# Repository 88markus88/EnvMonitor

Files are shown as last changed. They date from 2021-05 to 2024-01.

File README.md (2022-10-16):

# EnvMonitor - ESP32
This project aims to create an environmental monitoring system, using ESP32 and multiple environmental sensors and make the data visible using <B>Blynk</B> (https://blynk.io/)

The project consists of both software code and the hardware description as KiCad and (partly) Fritzing files.

It is work in progress, but already functional. Development is being done using Platformio with the Arduino platform. 
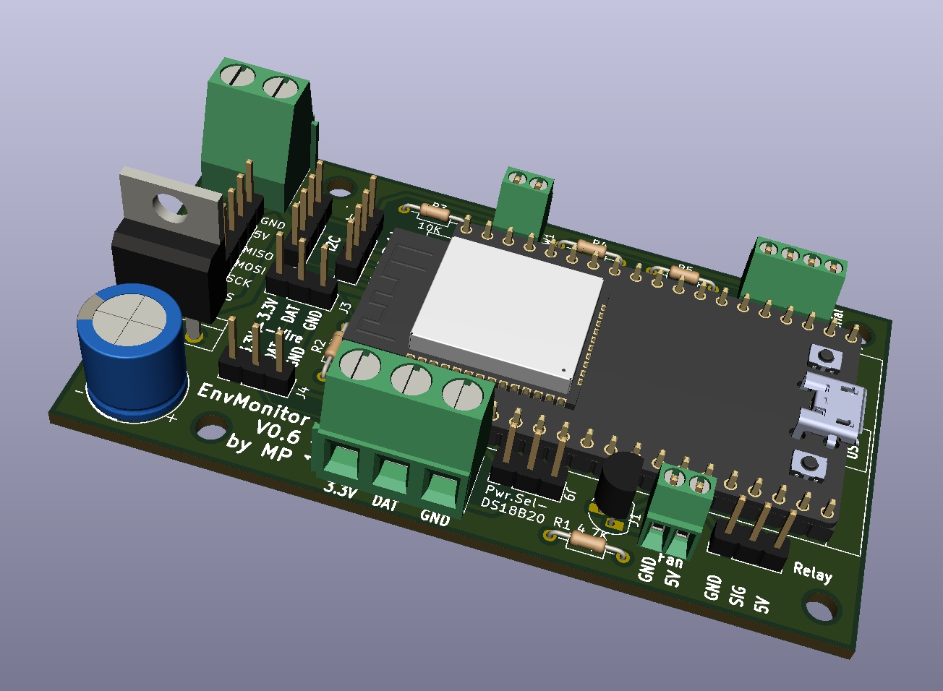
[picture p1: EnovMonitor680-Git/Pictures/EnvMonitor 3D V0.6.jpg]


## Visualization:
Visualization is done via Blynk, a commercial service that can also be used with a local server, e.g. on a Raspberry Pi
All data that the EnvMonitor provides can be shown via the Blynk App - very simple and powerful. Since the service is cloud based, the data can be viewed at every location.
Blynk also supports a local server (e.g. on a Raspberry) - this eliminates the costs for the Blynk service.

Support is also implemented for Thingspeak (all devices) and for Virtuino (early prototype).
Thingspeak is one-way only for BME280, BME600, DS18B20, 433 MHz external sensors and CO2 sensors. Each ESP32 board can be connected to one Thingspeak channel, up to 8 data per devices (data streams) are supported by Thingspeak.

## Sensors:
So far the following sensors and devices on the following list can be included. Selection is done by modification of the #defines in *GlobalDefines.h*:
- BME280 (Temperature / Humidity / Pressure) via I2C
- BME680 (Temperature / Humidity / Pressure / Air Quality) via I2C
- DS18B20 (Temperature, up to 3 sensors) via OneWire
- MH-Z14A (CO2) via Serial2
- SenseAir S8 (CO2) via Serial2
- External temperature and humidity data from an Infactory NV5849 433MHz transmitter connected to an Arduino via Serial2
- Infactory NV5849 (433 MHz Temperature / Humidity sender) directly received via 433MHz receiver at GPIO 33. This option is supported by the software, ut not implemented on the board. 

## Devices:
- Relays / Transistor switches (2). Used for fan and for piezo buzzers.
- OLED Display 0.94" (SS1306) via I2C
- LCD Display 4 x 20 via I2C
- Button to be able to switch content of displays, or mute display light
- SD card reader via SPI

## ESP32 Hardware
The main component is an ESP32 with various peripherals attached. Communication to the peripherals is done via 
- 1Wire (DS180B20 temperature sensors)
- I2C (OLE or LCD displays, BME280 or BME 680 environment sensors
- SPI (SD card drive)
- Serial (CO2 sensors, external sensors via Arduino)
- GPIOs (button, transistor or relais)

All components are optional. They can be used in a large varity of combinations, providing that there are no confliting requirements
- Multiple devices can be combined on the I2C interface. E.g. BME280 and OLED display can be used together. Or LCD display and BME680. Or BME280 and no display.
- Up to 3 DS18B20 temperature sensors are supported. 3 connectors are provided, where they are connected in parallel. 
- Only one serial port (Serial2) is supported. Therefore only one CO2 sensor, or alternatively one Arduino, can be connected.
- Running a fan, piezo buzzer etc. via BC547 transistor, or other devices via relay, is supported by the hardware. Can also be used for a buzzer which gives an alarm uf window remains open too long.
- An internal power source can be used, which requires 7V-36V input from an external power supply.
Components that are not used do not have to be placed on the board. They can be configured out in the software via #defines

The board can be powered via USB. However, the USB power is relatively unstable. Most USB power supplies are not stabilized and should not be used, at least with multiple components connected - this can lead to brownouts and system failure. Raspberry Pi power supplies are better suited. 
Best is to use the option to add an internal DCDC converter <I>Traco TSR 1-2450E</I> that can be driven with 7-36V and provides excellent power conditioning. If this is not chosen, just leave the components (DCDC converter, capacitor, diode, terminal block) out.

It is possible to receive data from a 433 MHz transmitter via serial (e.g. received from an Arduino). (The serial port is not included in the Fritzing drawing.) 
The Arduino board, as well as it's software are described in a separate section. 

The board allows power selection for the 1Wire bus: either directly from 3.3V, or via GPIO32 of the ESP32. (In default configuration each GPIO can drive 20 mA).
This is useful to be able to completely reset the 1Wire bus - often necessary if cheap DS18B20 ("fake sensors") are being used. These have a tendency to hang after extended use, the only viable option is then to completely cut the power.

KiCad files are provided for the electrical schemas and the PCB boards. 

There is also a Fritzing file for illustration, however it is not complete: it does not contain the option to connect a 433 MHz transmitter. It also does not contain the external power supply that has been included in KiCad, and the option to power the DS18B20 sensors via digital output 32 (Jumper on J9) as an alternative to 3.3V. This may be necessary if the sensors are too unstable for continued operation, they can then optionally be reset by switching their power supply. May be necessary since most available DS18B20s are fake and prone to unstability (no data for longer periods). First option in this case is the reduction of the pulllup resistor R2 to 2.5K.

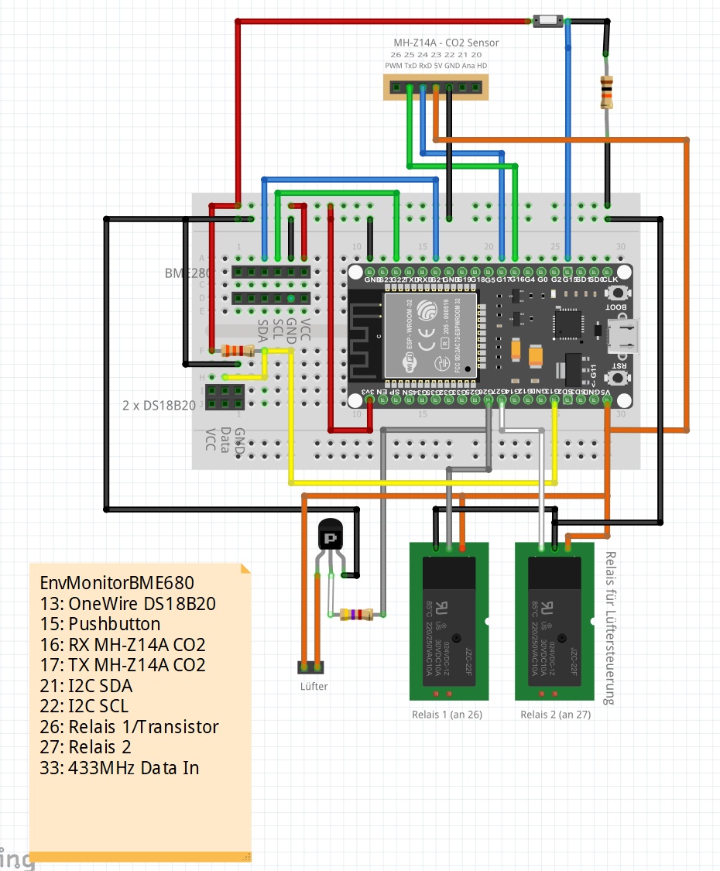
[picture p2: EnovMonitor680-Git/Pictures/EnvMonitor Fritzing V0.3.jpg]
Fritzing

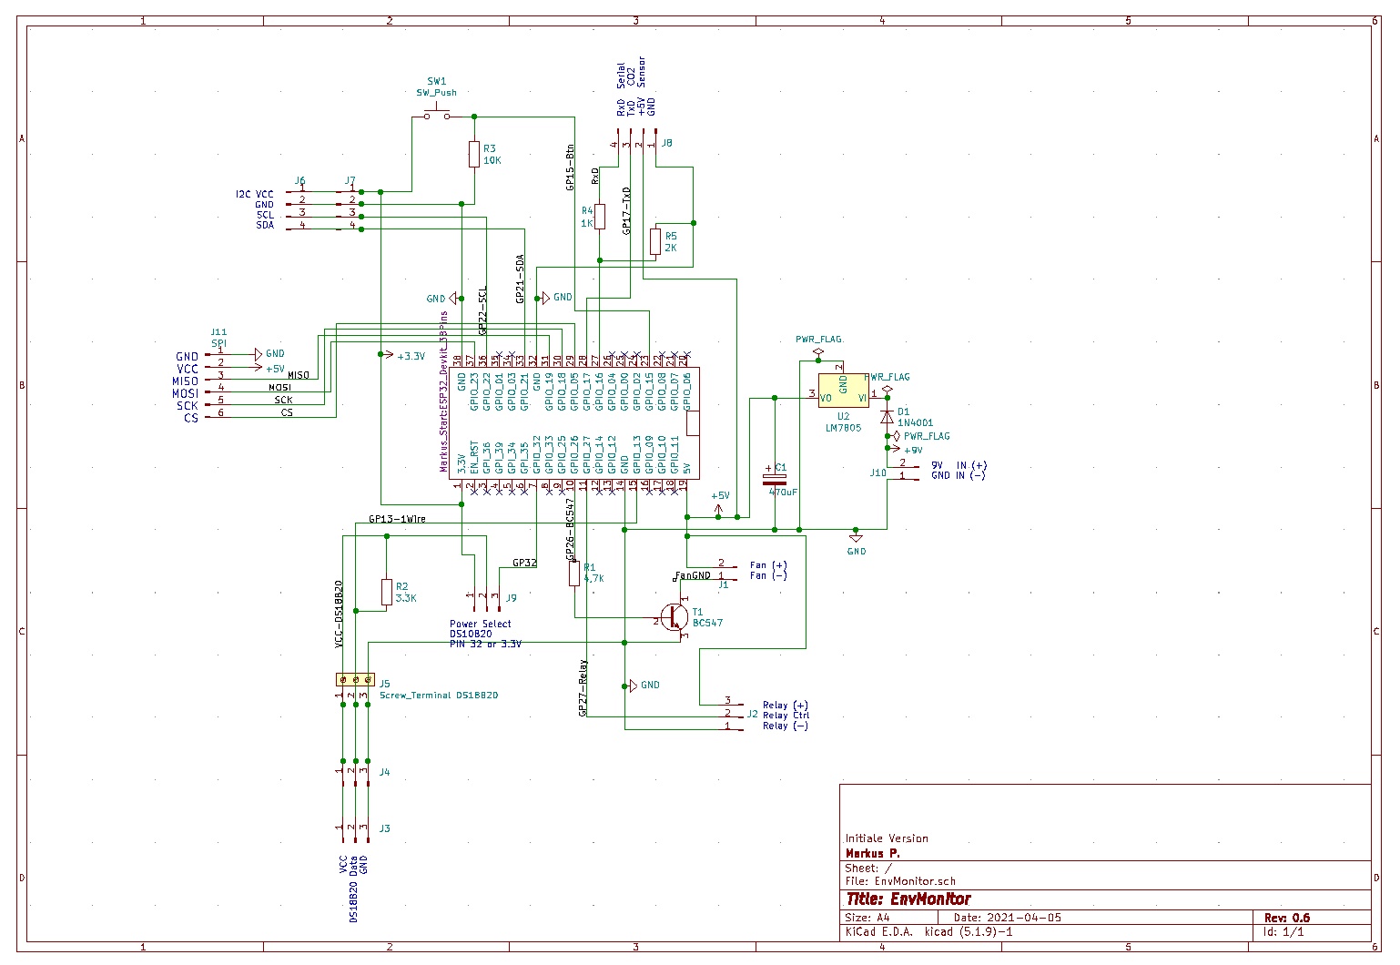
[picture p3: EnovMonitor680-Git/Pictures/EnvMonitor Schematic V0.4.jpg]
Schema

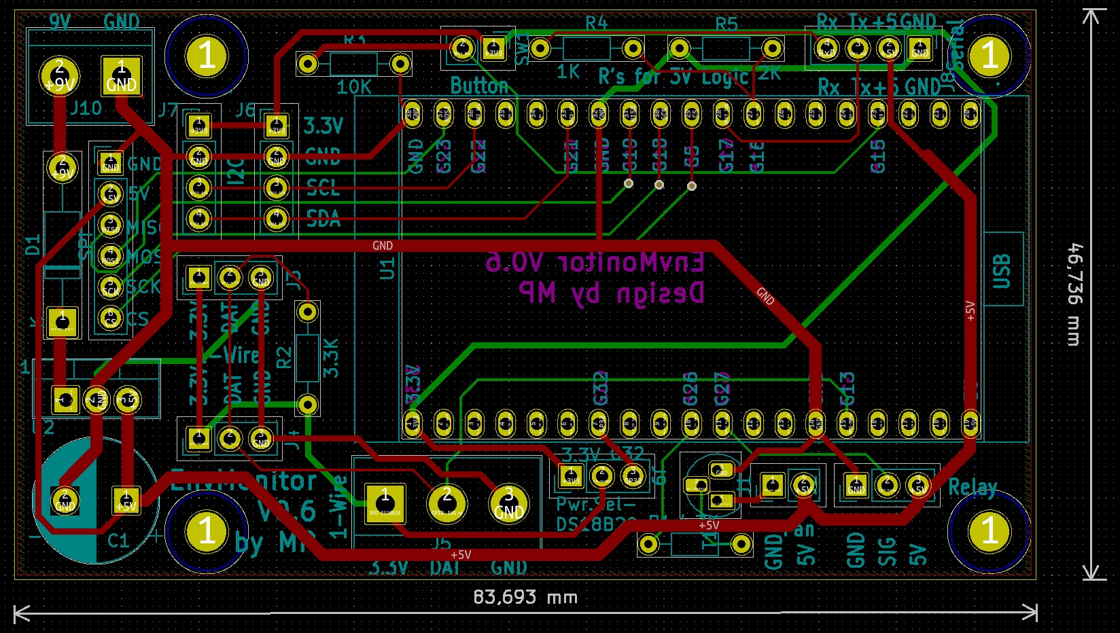
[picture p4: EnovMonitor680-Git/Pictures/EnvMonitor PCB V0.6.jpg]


## ESP32 Code
The code is written in C++. It is intended to be flexible, to allow almost any combination of sensors and displays on the board. 
All data are sent to a Blynk server, provided that *#define isBlynk* is set.

Development platform is Platformio. The code should also compile - with minimum adaptations - on the Arduino IDE. However, Platformio is much more flexible, compile times much faster due to more efficient built. It is well worth to switch to Platformio!

In order to compile the code, the following adaptations have to be made:
1. Get the required libraries, adjust the library path in *platformio.ini* to point to your library directory
2. create your own *Credentials.h* file. A template file is provided. You need to put in the name and password for your Wifi network, this is a must to allow the ESP32 to access the network. Then insert the auth code, temperature correction data and device info strings for each device you want to use. This file can contain any number of these device definitions, each within a #ifdef /#endif construct.
3. Adapt "GlobalDefines.h" to your hardware.  
  - enter the IP address of your local Blynk server
  - set one #define for the name of the hardware configuration you want to use (one of those in the "credentials.h" file)
  - set the actual hardware definitions: use of Blynk, use of sensors, use of display etc. These hardware definitions must fit the ones set in *credentials.h*
  - determine if you want to log to a SD card and / or to the serial port
  - determine if OTA (over the air) updates shall be used
 4. modify *platformio.ini* as needed: set _default_envs_ to determine which environment is to be used. This is largely required to determine if USB  upload or OTA upload to a given IP are to be used.

## Libraries
For listing of used libraries see 
See  [Libraries](https://github.com/88markus88/EnvMonitor/blob/main/EnovMonitor680-Git/Doc/Libraries.md)

## Connectivity 
In order to transmit data to a web service the ESP32 needs to log into a local network. At present, three services can be supported
- <b>Blynk</b>: Commercial service to which the data are sent, and shown on mobile device in an app that can be configured very fleibly. The data can either be sent to the Blynk web service or to a local server. fully implemented for all data. Temperature, Humidity, Pressure etc. for all sensors are transmitted via "Virtual Pins" (see below for details). Blynk Auth Codes, which are specific for any devices and generated within the Blynk App on a mobile device, need to be put into the file <i>Credentials.h</i>
<b>Notice</b> Blynk is presently transitioning to V2.0 with much more expensive licensing models, and no local server. Makes it less desirably for hobbyist users, consider Thingspeak as an alternative.
- <b>Virtuino</b>: (Experimental) Similar solution to Blynk. However, here the device itself provides a web server into which the mobile has to log in. Only partly implemented for demonstration purposes.
- <b>Thingspeak</b>: Web service that stores sensor data and makes them available to a variety of generic mobile apps. Data for all devices and sensors (BME680, BME280, CO2 Sensors and DS18B20 can be transmitted, as well as data from 433 MHz radio sensors for temperature and humidity. Thingspeak is addressed via a https call to an address that encodes the Write API Key defined for a specific device, there can be up to 8 data channels per device. The channel to be used is encoded via  <i>thingspeakWriteAPIKey</i>. Limitation are the up to 8 data items per channel and max 4 channels (=devices) per user in the free version. Also, the data rate is limited for the free version. This is taken care of by filtering the data to thingspeak, they are only updated if a significant change has been registered.
Blynk and Thingspeak can be used in parallel on a device. 
Settings which connecitivity type is used are done in <i>GlobalDefines.h</i> via the #defines isBLYNK, isThingspeak, isVirtuino. 

### Setting the WiFi Credentials
To access the local network the ESP32 requires the network credentials, particularly the SSID and password. They could be encoded in source code, and indeed default data are included in <i>Credentials.h</i>. However, this method is very clumsy - it requires re-compile of the code every time the credentials are changed, or a new network is used. Therefore, two methods are provided to update the credentials at runtime, and store them in the Preferences (ESP32 EEPROM):
- <b>Captive Portal</b> Activated by the #define <i>isCaptivePortal</i>. If this is set, the device goes through a sequence at bootup: 
1. If Wifi login with valid credentials are stored in the preferences, these are used
2. If not, the captive portal is opened, the user can select a network and provide the password. If login with these data is possible, these credentials are stored in the preferences for future use. The default SSID for the captive portal is <i>ESP_Config</i>  , the default password is <i>12345678</i>
3. If neither works, the defaults are used (but not stores, since the network may be out temporarily)
- <b>Bluetooth</b> Activated by the #define <i>isBluetoothCredentials</i>. When activated, the ESP32 waits for 60 sec after Boot for a connection from a mobile device. In a Bluetooth terminal app on the mobile, the user can then connect to the device, and enter the credentials: <i>ssid:[id_of_your_network]<i/> <i>pass:[your_password]<i/>. These credentials are then stored in the Preferences and used in future logins

### Blynk Virtual Pins
Blynk uses the concept of __Virtual Pins__ for communication between the hardware devices and App (via the server). The list of virtual pins in actual use depends on the sensors that are implemented on a specific devices. They need to be known in order to connect the Widgets within the App to specific sensors.

See [List of Virtual Pins](https://github.com/88markus88/EnvMonitor/blob/main/EnovMonitor680-Git/Doc/BlynkVirtualPins.md)

# Arduino
PCB and Code for the Arduino Nano that can provide the data from an external 433MHz sensor is also included.
Why using and Arduino? It turns out that the Wifi used by the ESP32 interferes with the 433 MHz reception when an ESP32 is used directly. The signals are disturbed by the 100 ms heartbeat of the Wifi that cannot be changed easily. 
So a small arduino PCB and sketch have been developed to still be able to use external 433MHz sensors. This Arduino needs to be connected via cable to the ESP32. Pins used for this are +5V, GND, RxD and TxD (the latter switched between ESP32 and Arduino)
No special libraries are needed for the Arduino Sketch. 

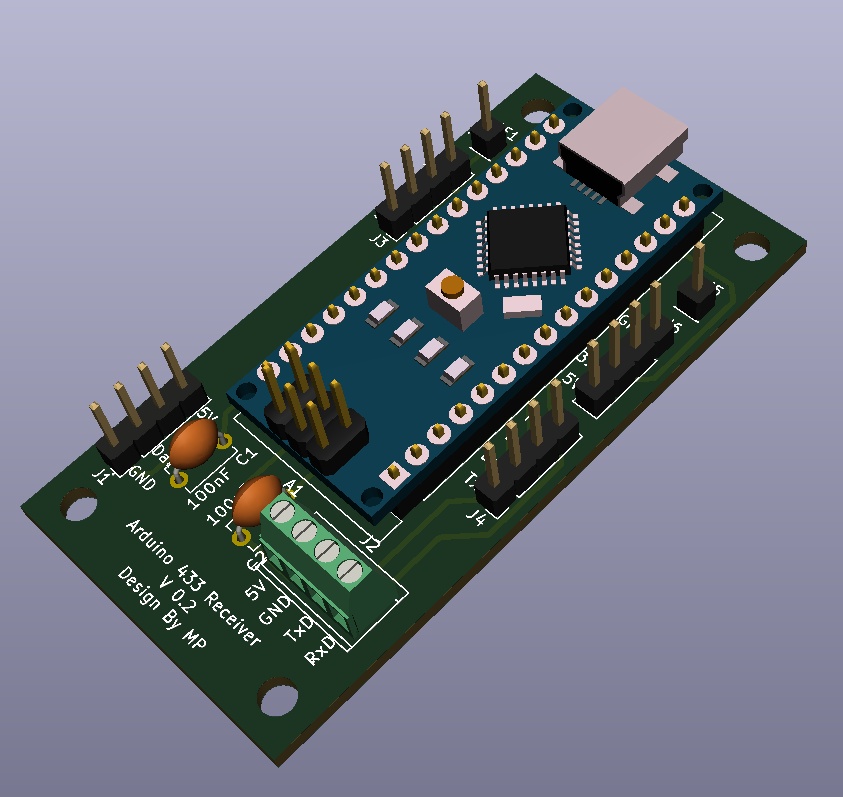
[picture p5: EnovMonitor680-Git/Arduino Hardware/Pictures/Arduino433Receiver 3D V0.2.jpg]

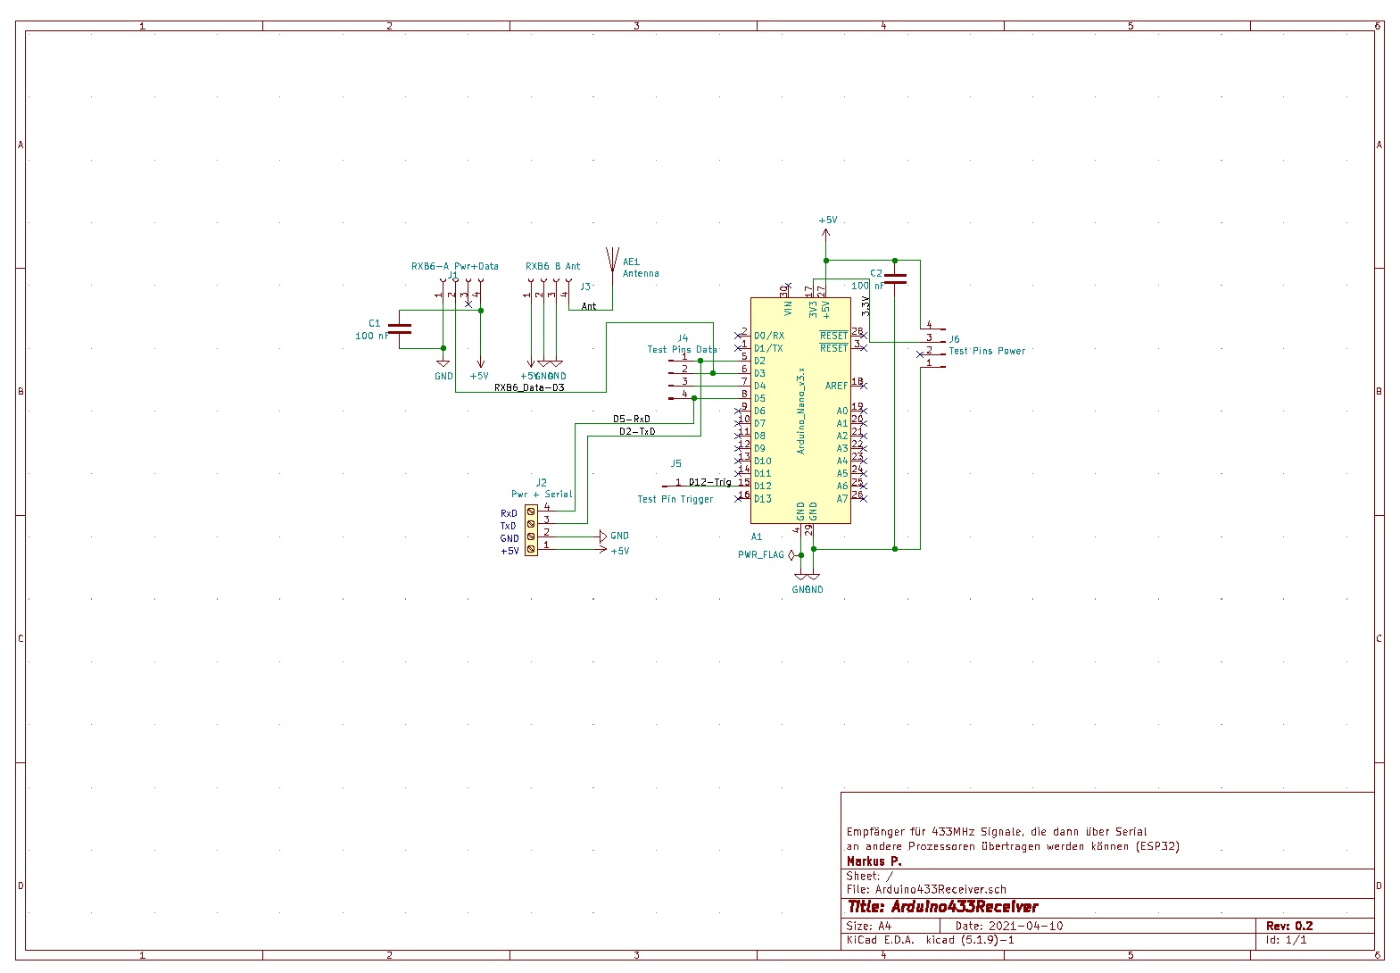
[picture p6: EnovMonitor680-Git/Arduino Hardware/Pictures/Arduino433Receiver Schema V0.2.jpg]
Schema

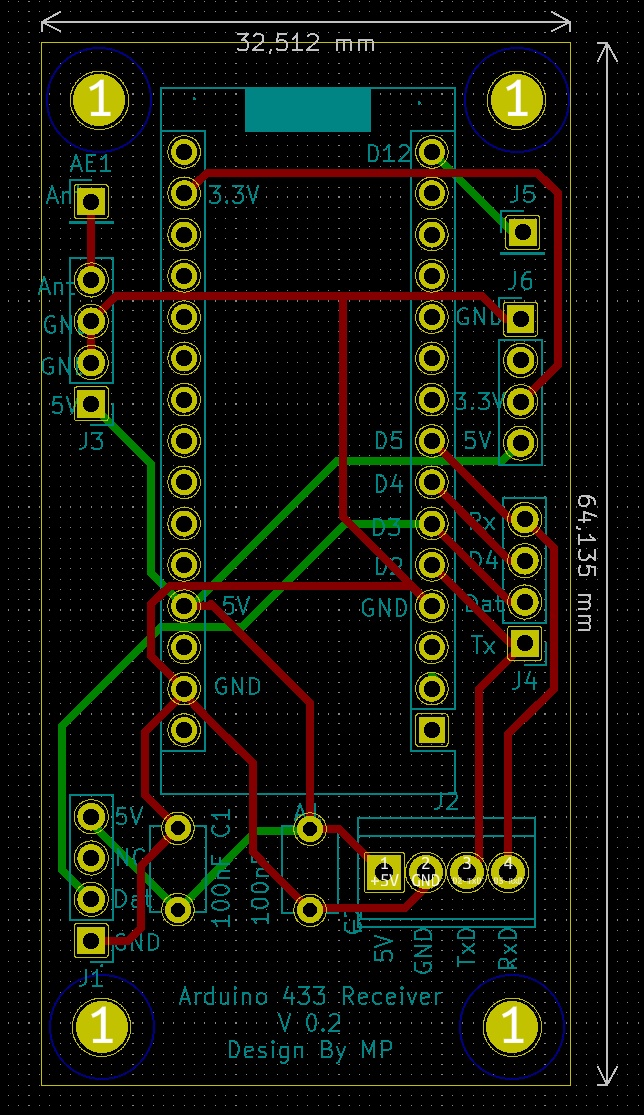
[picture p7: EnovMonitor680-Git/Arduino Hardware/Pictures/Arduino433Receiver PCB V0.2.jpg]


## Parts
See [Parts List](https://github.com/88markus88/EnvMonitor/blob/main/EnovMonitor680-Git/Doc/Partslist.md)

## GPIO Pins
A number of ESP32 I/O Pins are used. 
See  [List of GPIO Pins](https://github.com/88markus88/EnvMonitor/blob/main/EnovMonitor680-Git/Doc/GPIOs.md)

## Credits
- Blynk Library from here: https://blynk.io/. Using <i>Wifi, WifiClient</i> and <i>BlynkSimpleEsp32</i> libraries
- BME 280: <i>Wire</i>, <i>Adafruit_Sensor</i> and <i>Adafruit_BME280</i> libraries
- BME 680: using <i>Zanshin_BME680</i> and <i>SPI</i> libraries by Arnd SV Zanshin, https://github.com/Zanduino/BME680  and Information from this Article https://wiki.dfrobot.com/Gravity__I2C_BME680_Environmental_Sensor__VOC,_Temperature,_Humidity,_Barometer__SKU__SEN0248 <br>
  Alternatively: BME 680 using the manufacturer supplied __BSEC__ library by Bosch Sensortec. This library is only available as pre-compiled object code. https://platformio.org/lib/show/6979/BSEC%20Software%20Library 
- NTP time using info from: https://randomnerdtutorials.com/esp32-date-time-ntp-client-server-arduino/ 
- OLED display: using <i>Adafruit_GFX</i> and <i>Adafruit_SSD1306</i> libraries
- DS18B20: using <i>OneWire</i> and <i>DallasTemperature</i> libraries
- SenseAir S8: using code from SFeli https://github.com/SFeli/ESP32_S8  
- MH-Z14A_ using code from the contributin by Mitch K https://www.hackster.io/kritch83/getting-started-with-the-mh-z14a-co2-detector-e96234 
- Infactory NV5849: based on work and code by Ray Wang https://rayshobby.net/reverse-engineer-wireless-temperature-humidity-rain-sensors-part-1/ 
- Macros for bit field manipulation by Shun Yan Cheung: http://www.mathcs.emory.edu/~cheung/Courses/255/Syllabus/1-C-intro/bit-array.html
- LCD library from Marco Schwartz: <i>LiquidCrystal_I2C</i> : https://github.com/marcoschwartz/LiquidCrystal_I2C/archive/master.zip

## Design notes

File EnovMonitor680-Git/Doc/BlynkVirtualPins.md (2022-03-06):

#Blynk Virtual Pins

The Blynk App receives data from Virtual Pins, and sends data to Virtual Pins.
The ESP32 program has to handle the same Virtual Pins via 
- BLYNK_WRITE - from App to ESP32
- Blynk.virtualwrite - from ESP32 to App
These data are provided via a Blynk server. This can either be the Blynk Cloud service, at a cost per widget, or on a local server.

More Information is available on the [Blynk Website](https://blynk.io/)

These virtual Pins are used by EnvMonitor:

**Inputs**
VPin  |Function
------|---------
V40 | Relay 1 (was V18)
V41 | Relay 2 (was V19)
V42 | tempSwitchOffset (Fan on if temp BS680 this much too high)
V20 | Start CO2 Sensor Calibration
V60 | Manual restart of 1Wire bus (DS18B20 Sensors)
V70 | Used for data transfer by bridge1. Transfer temperature alerts.
V80 | Used for data transfer by bridge2. Transfer temperature alerts.

**Outputs**
VPin  |Function
------|---------
V1  | Wifi Signal strength (RSSI)
V5  | BME280 / BME680 Temperature
V6  | BME280 / BME680 Air Pressure
V7  | BME280 / BME680 Humidity
V8  | BME680 Air Quality Score
V12 | BME680 Air Quality String
V13 | DS18B20[0]  Temperature
V10 | DS18B20[1]  Temperature
V11 | DS18B20[2]  Temperature
V15 | Infactory Temperature Ch1
V16 | Infactory Humidity Ch1
V17 | Infactory Temperatue Ch2
V18 | Infactory Humidity Ch2
V19 | Infactory Temperature Ch3
V20 | Infactory Humidity Ch3
V35 | Infactory Ch1 Counter 
V36 | Infactory Ch2 Counter 
V37 | Infactory Ch3 Counter 
V38 | Infactory Serial Fail Counter

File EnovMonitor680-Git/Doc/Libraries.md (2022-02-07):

# EnvMonitor 

## Libraries
The libraries for ESP32 include:
- Syslog 2.0.0 - for writing of log data to a syslog server 
- DNSServer 1.1.0 - used for captive portal
- EEPROM 1.0.3 - outdated. Writing of permanent data to ESP32 EEPROM 
- Preferences 1.0 - Writing of permanent data to ESP32 EEPROM 
- WiFi 1.0 - Base library for all WiFi functions
- WifiClientSecure 1.0 - a base library for HTTPS access
- ESPmDNS 1.0 - a base library for HTTPS access
- ESP32Ping 1.7 - a base library for HTTPS access
- HTTPClient 1.2 - enables to set up a captive portal, which is used to set the device's WiFi access data
- LiquidCrystal_I2C - to write information on a LCD display
- SimpleTimer - timer functions, used if no Blynk timer is available
- BluetoothSerial 1.0 - to enable setting of device's WiFi access data via bluetooth
- FS 1.0 - file system base functions, used for SD cards
- SD(esp32) 1.0.5 - handing of SD cards
- BME680 1.0.10 - library for BME 680 (if no precompiled libraries by BSEC are used)
- Precompiled BSEC Library for BME680
- Adafruit BME280 Library 2.1.2 - Adafruit library for BME280 sensor
- Adafruit GFX Library 1.7.5 - basic graphic library
- Adafruit Unified Sensor 1.1.4 - generic sensor library
- Adafruit SSD1306 2.1.0 - to write information on a OLED display
- ArduinoOTA 1.0 - enables update of the ESP32 firmware via over-the-air transmission (OTA)
- Update 1.0  - base library for OTA update
- Blynk 0.6.1 - enables connection to Blynk server for display of all data on a mobile device
- DallasTemperature 3.9.0 - DS18B20 temperature sensor
- OneWire 2.3.5 - base library for access to DS18B20 
- SPI 1.0 - base library for SPI devices (BME280, BME680, OLED, LCD)
- Wire 1.0.1 - base libary for SPI devices 

Dependency Tree in PlatformIO:
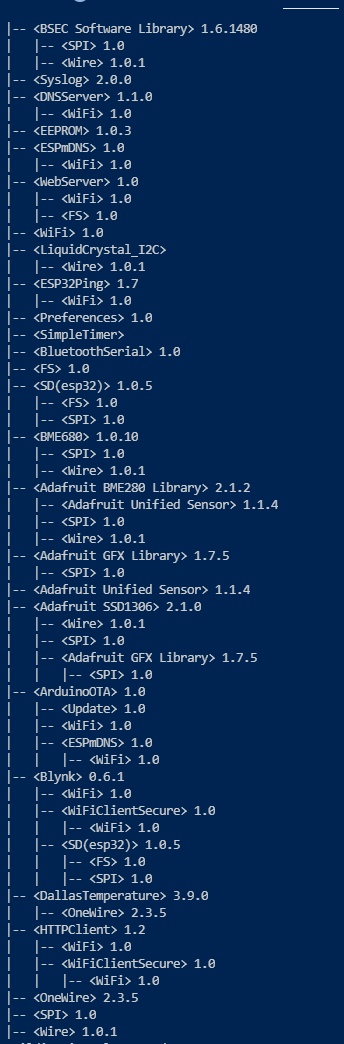
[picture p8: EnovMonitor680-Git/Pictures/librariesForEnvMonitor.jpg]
Libraries


# Arduino

## Libraries

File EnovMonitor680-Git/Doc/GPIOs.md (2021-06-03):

#GPIO Pins used in EnvMonitor

These GPIO Pins are used by EnvMonitor:
**Inputs and Outputs**
GPIO |Function| Comments
------|-------|--
5 | SPI CS | SD Card Reader
13 | OneWireDS18B20 | 1 Wire data for DS18B20 sensors
14 | LED output | to show that system is alive
15 | Pushbutton | push button input, 
16 | Serial RX | MH-RX 14A CO2, Senseair S8 CO2 or Arduino serial data (only one of these at any time)
17 | Serial TX | MH-RX 14A CO2, Senseair S8 CO2 or Arduino serial data (only one of these at any time)
18 | SPI SCK | SD Card Reader
19 | SPI MISO | SD Card Reader
21 | I2C SDA | OLED display, LCD display , BME 280 sensor, BME 680 sensor 
22 | I2C SCL | OLED display, LCD display , BME 280 sensor, BME 680 sensor 
23 | SPI MOSI | SD Card Reader
26 | BC 547 | Transistor to switch fan etc. 
27 | Relais 2 | relais output. presently not used
32 | OneWire Power | 3.3 V power via GPIO allows to switch 1Wire off for reset
33 | 433MHz Data In | in case that a 433 MHz receiver is directly connected. presently not used

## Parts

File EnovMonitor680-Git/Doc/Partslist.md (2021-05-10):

# EnvMonitor 

## Parts List
- PCB for ESP32 (e.g. from JLCPCB)
Can be ordered 
- [ESP32 DevKit C](https://www.amazon.de/gp/product/B074RGW2VQ/ref=ppx_yo_dt_b_search_asin_title?ie=UTF8&psc=1)
- Resistors. One each 4,7K, 10K, 1K, 2K, 3.3K
- [Transistor BC 547](https://www.reichelt.de/bipolartransistor-npn-45v-0-1a-0-5w-to-92-bc-547a-cdil-p5005.html?&trstct=pos_1&nbc=1)
- [Terminal Block 3x, 5,08 mm spacing](https://www.reichelt.de/leiterplattenklemme-3-polig-rm-5-08-mm-dg127-5-08-3-p276157.html?&nbc=1)
- [2 Terminal Block 3x, 2,54 mm spacing](https://www.reichelt.de/leiterplattenklemme-3-polig-rm-2-54-mm-dg308-2-54-3-p276215.html?&trstct=pol_1&nbc=1)
- [5-9 Terminal Block 2x, 2,54 mm spacing](https://www.reichelt.de/leiterplattenklemme-2-polig-rm-2-54-mm-dg308-2-54-2-p276214.html?&nbc=1)
- 2 Pinheader female 4x 2,54 mm spacing
- Pinheader male 3x
- [OLED display 0.96'](https://www.amazon.de/AZDelivery-Display-Arduino-Raspberry-gratis/dp/B01L9GC470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) 
or [LCD display (I2C) 4x20](https://www.amazon.de/AZDelivery-HD44780-Display-Zeichen-Schnittstelle/dp/B07N8CGM9G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)
- Button
- Housing

**For power supply:**
- [Terminal Block 2x, 5,08 mm spacing](https://www.reichelt.de/leiterplattenklemme-2-polig-rm-5-08-mm-dg129-5-08-2-p276166.html?&nbc=1)
- [DCDC Converter Traco TSR 1-2450E](https://www.reichelt.de/dc-dc-converter-tsr-1e-1-a-7-36-5-0-vdc-sip-3-tsr-1-2450e-p288648.html?&nbc=1)
- [Diode 1N4001](https://www.reichelt.de/gleichrichterdiode-50-v-1-a-do-41-1n-4001-p1723.html?&nbc=1)
- Electrolyte Capacitor 470 uF
- [Connector for power supply 9V, 2.1 mm](https://www.reichelt.de/einbaubuchse-zentraleinbau-aussen-5-6-mm-innen-2-1-mm-hebl-21-p8524.html?&nbc=1)

# Arduino

## Parts List
- PCB for Arduino (e.g. from JLCPCB)
- [Arduino Nano](https://www.amazon.de/gp/product/B078SBBST6/ref=ppx_yo_dt_b_search_asin_title?ie=UTF8&psc=1)
- [433 MHz Receiver RXB6](https://www.amazon.de/gp/product/B07DK6VF3W/ref=ox_sc_saved_title_8?smid=A3SCFTIO8CSK1X&psc=1)
- [433 MHz Antenna](https://www.amazon.de/Antenne-Helical-Antenne-Fernbedienung-Arduino-Raspberry/dp/B00SO651VU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)
- 2 x Capacitor 100 nF
- Terminal Block 4x, 2,54 mm spacing
- Two Pinheader: 4x, 2,54 mm spacing  (used for debugging only)
- Housing

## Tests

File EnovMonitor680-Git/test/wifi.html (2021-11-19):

## WiFi Settings

Current ESP 32 WiFi Settings:
Mode | Soft Access Point (AP)
SSID | "MyWiFiConfig.APSTAName"

Current ESP 32 WiFi Settings:

Mode | Soft Access Point (AP)
SSID | "MyWiFiConfig.APSTAName"

Available WiFi Networks:

No | SSID | Encryption | WiFi dB
1 | Fritz7390-Gast | WPA/WPA2 4 | -76
2 | Fritz7390-MP2.4 | WPA/WPA2 4 | -77
3 | Dumbledore | WPA2 3 | -78

Connect to WiFi SSID:
WiFi Password:

Save Client Wifi Settings

WiFi Access Point Settings

WiFi Access Point Name:
WiFi Password:
Repeat WiFi Password:

Login Password required Captive Portal active
Save Portal Wifi Settings

Reboot System Reset Access Point settings

System Links:

Main Page

Markus Status Page

Programmed and designed by: Markus P.

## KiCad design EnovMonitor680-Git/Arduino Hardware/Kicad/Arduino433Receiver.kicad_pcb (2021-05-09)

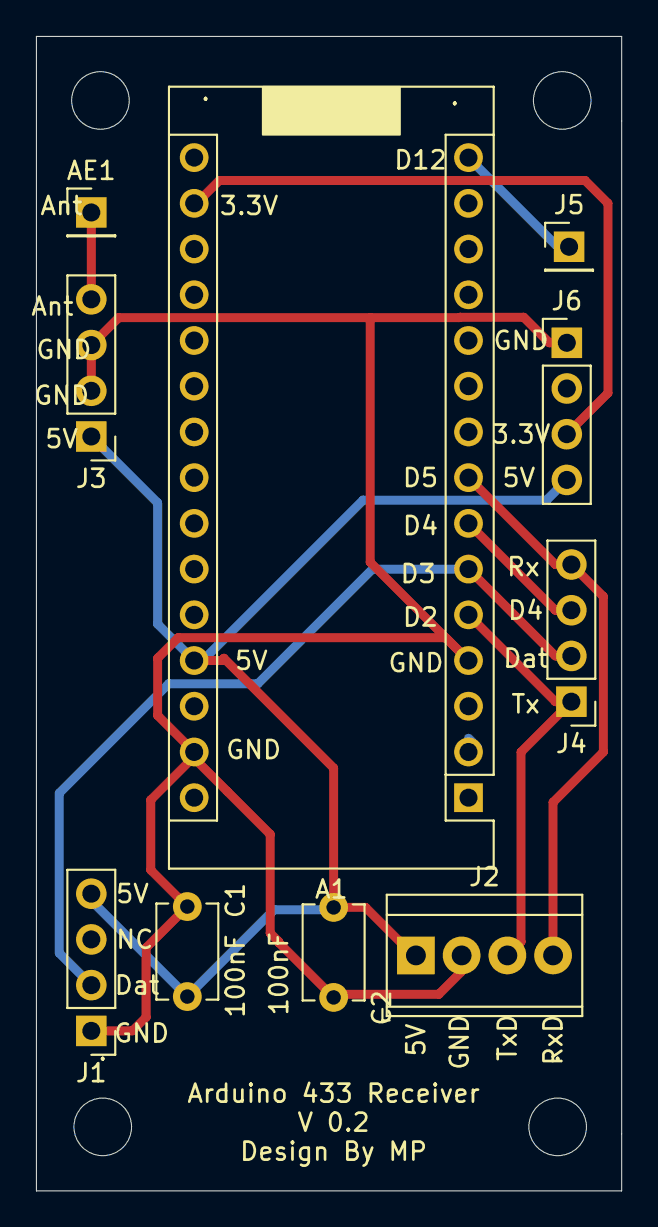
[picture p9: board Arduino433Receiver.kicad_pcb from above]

Board: 2 copper layers, 32.5 x 64.1 mm, 14 parts (0 on the bottom side), 9 nets.

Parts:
., .#2, .#3, .#4: MountingHole_3.2mm_M3
A1: Arduino_Nano_v3.x; Arduino_Nano
AE1: Antenna; PinHeader_1x01_P2.54mm_Vertical
C1, C2: 100 nF; C_Disc_D5.1mm_W3.2mm_P5.00mm
J1: RXB6-A Pwr+Data; PinHeader_1x04_P2.54mm_Vertical
J2: Pwr + Serial; TerminalBlock_TE_282834-4_1x04_P2.54mm_Horizontal
J3: RXB6 B Ant; PinHeader_1x04_P2.54mm_Vertical
J4: Test Pins Data; PinHeader_1x04_P2.54mm_Vertical
J5: Test Pin Trigger; PinHeader_1x01_P2.54mm_Vertical
J6: Test Pins Power; PinHeader_1x04_P2.54mm_Vertical

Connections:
+5V: A1.27, C1.1, C2.1, J1.4, J2.1, J3.1, J6.4
/3.3V: A1.17, J6.3
/Ant: AE1.1, J3.4
/D2-TxD: A1.5, J2.3, J4.1
/D5-RxD: A1.8, J2.4, J4.4
/D12-Trig: A1.15, J5.1
/RXB6_Data-D3: A1.6, J1.2, J4.2
GND: A1.4, A1.29, C1.2, C2.2, J1.1, J2.2, J3.2, J3.3, J6.1
unnamed: A1.7, J4.3

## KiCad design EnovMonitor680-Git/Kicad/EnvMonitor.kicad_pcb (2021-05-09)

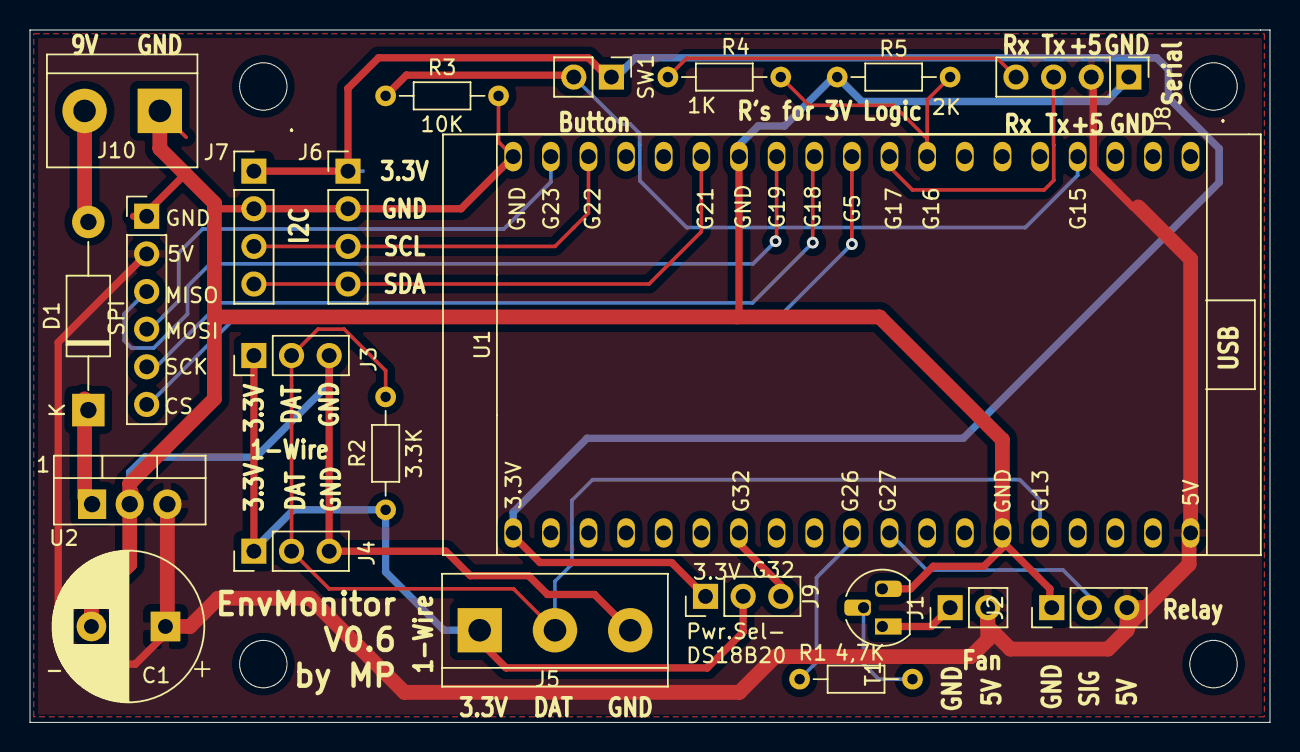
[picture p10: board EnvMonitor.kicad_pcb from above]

Board: 2 copper layers, 83.7 x 46.7 mm, 26 parts (0 on the bottom side), 22 nets.

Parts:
., .#2, .#3, .#4: MountingHole_3.2mm_M3
C1: 470uF; CP_Radial_D10.0mm_P5.00mm
D1: 1N4001; D_DO-41_SOD81_P12.70mm_Horizontal
J1: Pinheader Fan; PinHeader_1x02_P2.54mm_Vertical
J2: Pinheader Relay; PinHeader_1x03_P2.54mm_Vertical
J3, J4: Pinheader DS18B20; PinHeader_1x03_P2.54mm_Vertical
J5: Screw_Terminal DS18B20; TerminalBlock_bornier-3_P5.08mm
J6, J7: Pinheader I2C; PinHeader_1x04_P2.54mm_Vertical
J8: Pinheader Serial; PinHeader_1x04_P2.54mm_Vertical
J9: Power Select; PinHeader_1x03_P2.54mm_Vertical
J10: Power In 9V; TerminalBlock_bornier-2_P5.08mm
R1: 4,7K; R_Axial_DIN0204_L3.6mm_D1.6mm_P7.62mm_Horizontal
R2: 3.3K; R_Axial_DIN0204_L3.6mm_D1.6mm_P7.62mm_Horizontal
R3: 10K; R_Axial_DIN0204_L3.6mm_D1.6mm_P7.62mm_Horizontal
R4: 1K; R_Axial_DIN0204_L3.6mm_D1.6mm_P7.62mm_Horizontal
R5: 2K; R_Axial_DIN0204_L3.6mm_D1.6mm_P7.62mm_Horizontal
SPI: SPI; PinHeader_1x06_P2.54mm_Vertical
SW1: SW_Push; PinHeader_1x02_P2.54mm_Vertical
T1: BC547; TO-92_HandSolder
U1: ESP32 Wroom AzDelivery; ESP32_Devkit_38Pins
U2: LM7805; TO-220-3_Vertical

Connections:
+3V3: J6.1, J7.1, J9.1, SW1.1, U1.1
+5V: C1.1, J1.2, J2.3, J8.2, SPI.2, U1.19, U2.3
+9V: D1.2, J10.2
/CS: SPI.6, U1.29
/GP13-1Wire: J3.2, J4.2, J5.2, R2.2, U1.15
/GP15-Btn: R3.1, SW1.2, U1.23
/GP17-TxD: J8.3, U1.28
/GP21-SDA: J6.4, J7.4, U1.33
/GP22-SCL: J6.3, J7.3, U1.36
/GP27-Relay: J2.2, U1.11
/GP32: J9.3, U1.7
/MISO: SPI.3, U1.31
/MOSI: SPI.4, U1.37
/RxD: J8.4, R4.1
/SCK: SPI.5, U1.30
/VCC-DS18B20: J3.1, J4.1, J5.1, J9.2, R2.1
GND: C1.2, J2.1, J3.3, J4.3, J5.3, J6.2, J7.2, J8.1, J10.1, R3.2, R5.1, SPI.1, T1.3, U1.14, U1.32, U1.38, U2.2
unnamed: D1.1, U2.1
unnamed: J1.1, T1.1
unnamed: R1.1, T1.2
unnamed: R1.2, U1.10
unnamed: R4.2, R5.2, U1.27

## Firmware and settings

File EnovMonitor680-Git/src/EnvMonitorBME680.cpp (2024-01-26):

// EnvMonitor for ESP32 with BME680, MH-Z14A CO2 Detektor, BME280, 2 DS18B20
// Deplay via Blynk on Smartphone / Tablet, also via #define
// Configurable via #defines, which Sensors are present
//
// Infos BME680:
// https://wiki.dfrobot.com/Gravity__I2C_BME680_Environmental_Sensor__VOC,_Temperature,_Humidity,_Barometer__SKU__SEN0248
// https://github.com/Zanduino/BME680 
// Pinblegung (I2C): (+) = VCC (3,3-5V) / (-) = GND / C = SCL / D = SDA
// ESP32: 21= SDA, 22 = SCL
// Connect + of the BME680 sensor to 3.3V 
// Connect - to Ground
// Connect C GPIO 22
// Connect D GPIO 21
//**************************************************************************************
// serial communication with winston CO2 sensor via UART
// https://circuits4you.com/2018/12/31/esp32-hardware-serial2-example/
// https://www.hackster.io/kritch83/getting-started-with-the-mh-z14a-co2-detector-e96234
// RX: GPIO 16 / TX: GPIO 17
//**************************************************************************************
// Blynk: Blynk uses Core 0 of the ESP32. Therefore, parallel processing to read the values of
// DS18B20 temp-sensors leads to faulty results, since blynk interrupts the measurements. 
// solution was to run the detached measurement procedure on core1 as all the rest
// and to use non-blocking delays (300 ms: vTaskDelay(300 / portTICK_PERIOD_MS);)
// which allow the measurement routint to run with no issues. Now almost each measurement is successful
//
// Blynk collides with data collection interrupt routine for 433MHz sensor temp/hygro. 
// all data for interrupt routine need to be "volatile" - otherwise the system crashes in data access
// interrupt routines should have the attribute IRAM_ATTR to ensure that they run in RAM = faster
// Blynk Needs to be switched off while collecting 433 data

// Device selection stuff. if these flags are set, all relevant code is included. 
// this is used to enable / disable the code for various sensors as part of the env-station
// (use define or undef)


//*** general libraries. Libraries that multiple modules use should reside here 
#include <Arduino.h>
#include "time.h"
#include <SimpleTimer.h>        // Simple Timer, used instead of Blynk timer for virtuino
#include <Preferences.h>        // used to permanently store data
#include <esp_task_wdt.h>       // Load Watchdog-Library
#include "GlobalDefines.h"      // global defines that determine what to compile
#include "HelperFunctions.h"    // prototypes for global helper functions
#include "EnvMonitorBME680.h"   // My main include file
#include "Infactory433.h"       // Infactory 433 Temp/Humid sensor
#include "SDFunctions.h"        // functions to handle SD memory card
#include "LCDFunctions.h"       // functions to handle LCD display
#include "ESP32Ping.h"          // ping library
#include "CaptivePortal.h"      // Captive Portal functions

//#include <cstring>
//#include <string>

void(* resetFunc) (void) = 0; //declare reset function @ address 0 THIS IS VERY USEFUL

// Write string on the SD card
#if defined logSD && defined isSD
  void logSDCard(char *printstring) 
  {
    // Serial.print("Save to SD: ");
    // Serial.println(printstring);
    appendFile(SD, logfilename, printstring);
  }
#endif  

// function to handle all logging output. To serial, into file on SD, to Blynk terminal
void logOut(char* printstring, unsigned int MsgID, unsigned int MsgSeverity)
  {
    char timestring[50]="";      
    char outstring[230];

    #ifdef isLEDHeartbeat
      heartbeatStatus = !heartbeatStatus;
      // digitalWrite (HEARTBEATPIN, heartbeatStatus);
      digitalWrite (HEARTBEATPIN, HIGH);
    #endif

    #ifdef getNTPTIME
      if(TimeIsInitialized)
      {
        printLocalTime(timestring, 5);
      }  
    #endif 

    #ifdef logSerial
      Serial.print(printstring);
    #endif

    #if defined logSD && defined isSD      
      strcpy(outstring, timestring);
      strcat(outstring, printstring);      
      logSDCard(outstring);
    #endif

    #if defined isBLYNK && defined blynkTerminal
      strcpy(outstring, timestring);
      strcat(outstring, printstring);
      myBlynkTerminal.print(outstring);
      myBlynkTerminal.flush();
    #endif

    #ifdef isLEDHeartbeat
      heartbeatStatus = !heartbeatStatus;
      digitalWrite (HEARTBEATPIN, LOW);
    #endif

    #ifdef isSyslog
      if(WiFi.status() == WL_CONNECTED)
      {
        sprintf(outstring, "%d %d %s", MsgID, MsgSeverity, printstring);
        syslog.log(LOG_INFO | LOG_USER, outstring);
        // Log message can be formated like with printf function.
        // syslog.logf(LOG_ERR,  "This is error message no. %d", iteration);  
        // Log Levels: LOG_INFO, LOG_ERR, LOG_DAEMON 
      }
    #endif

    #ifdef isMQTTLog
      char topicStr[200];
      sprintf(topicStr,"esp32/%s/log/%d/%d",mqttRoomString, MsgID, MsgSeverity);
      strcpy(outstring, timestring);
      strcat(outstring, printstring); 

      //sprintf(printstring, "test logOut 2. Topic: _%s_ _%s_ %d",topicStr, outstring, strlen(outstring));
      //Serial.print(printstring);
      if(mqttClient.connected())
        mqttClient.publish(topicStr, outstring, strlen(outstring)); //payload: outstring
      //sprintf(printstring, "test logOut 2");  
      //Serial.print(printstring);
    #endif

  }

#ifdef isDisplay

  // Display class based on AdafruitGFX, special type SSD1306
  Adafruit_SSD1306 display(SCREEN_WIDTH, SCREEN_HEIGHT, &Wire, OLED_RESET);

  /**************************************************!
  @brief    Display one string on OLED display
  @details 
  @param string String to be displayed
  @param size Text size in multiples of standard. 1: normal, 2: double ....
  @param x  x-position of text
  @param y  y-position of text
  @param clear boolean flag, determines if display is cleared before text output
  @return   void
  ***************************************************/
  void Display(char *string, int size, int x, int y, boolean clear)
  {
    if (clear) display.clearDisplay();
    display.setTextSize(size);
    display.setCursor(x, y);
    display.println(string);
    display.display();
  }
#endif

#ifdef isOneDS18B20

  volatile unsigned long LastMeasTimer;
  const long ds18b20MeasInterval = 1000; // measure every xxx ms

  // mutex could be needed for critical section, not implemented
  // static portMUX_TYPE my_mutex = portMUX_INITIALIZER_UNLOCKED;

  /**************************************************!
  @brief    Function to measure DS18B20 temperatures in endless loop. Designed to run in parallel
  @details  This task runs isolated on core 0 because sensors.requestTemperatures() is slow and blocking for about 750 ms
            gets temperature from DS18B20 via OneWire
            Temperature is measured by address, not by indes. This ensures that there is no mismatch, if a sensor
            goes temporarily offline (as fake sensors occasionally do)
            Does some checking. Sensor values indicate errors if out of range:
              -127: bad reading. 85: no measurement yet (to early after a restart)
            Uses global variables:
            - measuringInfactoryOngoing : If this flag is set, no measurements are taken (to not disturb timing)
            - stopDS18B20MeasureFlag : If this flag is set, no measurements are taken (to not disturb timing)
            - noDS18B20Connected : Number of DS18B20 which are connected
            - DS18B20Address[i][j] :  Address of Sensor i, each 8 bytes long (j= 0..7)
            Returns global variables
            - DS18B20Temperature[i] : raw measured temperature in °C for each sensor
            - LastMeasTimer : timer mark when last measurement has been done
            - notChangedCount : global counter for not changed values. Used to determine if measurements stopped
            - GetOneDS18B20Counter : global counter for cycles through this procedure. Used to determine if measurements stopped
  @param    parameter   Task input parameter, not used. Required for starting function
  @return   void
  ***************************************************/
  void GetOneDS18B20Temperature( void * parameter) 
  {
    float tmp1 = 0;
    // float tmp2 = 0;
    static int i,j;
    int localInfactoryFlag = false;
    uint8_t addr[8];          // uint8_t = unsigned char, 8 bit integer

    #ifdef isInfactory433
      localInfactoryFlag = measuringInfactoryOngoing; // if infactory sensor connected, use global flag - otherwise always false
    #endif

    for (;;) {   // Endless loop
      if(millis()-LastMeasTimer > ds18b20MeasInterval)
      // there should be noDS18B20Connected sensors attached
      {
        if(localInfactoryFlag == false && stopDS18B20MeasureFlag == false)   // do not take measurements if infactory 433 MHz sensor is queried
        {
          sensors.requestTemperatures(); // Send the command to get temperatures
          // vTaskDelay(100);
          LastMeasTimer = millis();
          for(i=0;i<noDS18B20Connected;i++)
          {
            for(j=0;j<8;j++){
              addr[j] = DS18B20Address[i][j];
              // if(addr[j]<16) Serial.print("0");
              // Serial.print(addr[j],HEX);
            }  
            // Serial.println("");

            //*** alternative: by index: tmp1 = sensors.getTempCByIndex(i);
            tmp1 = sensors.getTempC(addr); 
            if(abs(DS18B20Temperature[i] - tmp1) < 0.01) // check: did the value change?
              notChangedCount++;              // global counter for not changed values
            else
              notChangedCount = 0;  
            if (tmp1 != -127 && tmp1 != 85)   //-127: bad reading. 85: no measurement yet 
            {
              DS18B20Temperature[i] = tmp1;
              Serial.print(i); 
              notMeasuredCount = 0;     // note that a measurement has been taken, set counter to zero
            }  else
            {
              DS18B20Temperature[i] = -111.11;
              Serial.print(":"); 
              LastMeasTimer = 0;
              notMeasuredCount++;       // note that measurements was not possible, increase counter
            }
          }
        }  
        else
        {
          sprintf(printstring,"No DS18B20 Measurement due to flag %d %d\n",
            localInfactoryFlag,stopDS18B20MeasureFlag);
          logOut(printstring, msgDS18B20NoMeasFlag, msgWarn);  
        }
      }
      else
      {
        vTaskDelay(200 / portTICK_PERIOD_MS); // delay for 200 ms
        // sprintf(printstring,"W %ld %ld ", millis(),LastMeasTimer);    
        // logOut(printstring, msgDefaultID, msgDefault);
        GetOneDS18B20Counter ++;  
      }  
    }
  }

  //---- the following procedure determines the number of DS18B20, sets their precision to 12 bit and stores their addresses
  DeviceAddress tempDeviceAddress;
  #define TEMPERATURE_PRECISION 12   // precision 9..12 Bit

  /**************************************************!
  @brief    Determine number of DS18B20 sensors on 1Wire Bus and determine their addresses
  @details  First attempts sensors.getDeviceCount() to determine the number of devices, which does not work presently
            Then sets temperature precision to 12 bits for 3 devices 
            Finally uses sensors.getAddress() to count how many devices actually present.
            Fills the following global variables:
            noDS18B20Connected                      : Number of DS18B20 actually present
            DS18B20Address[noDS18B20Connected][i]   : their addresses
  @param    none
  @return   void
  ***************************************************/
   void adresseAusgeben(void) {
    byte i, j, k;
    uint8_t addr[8];          // uint8_t = unsigned char, 8 bit integer
    int numberOfDevices, noRepeats;
    char ps[80];
    long checksum[5], sum1, sum2;         // address checksums
    bool check, crcCheck;

    // loop to determine the addresses of the DS18B20 sensors. 
    // Repeat in case of crc check failure or duplicate addresses
    noRepeats = 0;
    do{
      esp_task_wdt_reset();   // keep watchdog happy
      // code 1: devices finden.
      // this method does not work for ESP32
      delay(1000);
      oneWire.reset_search(); // reset search of oneWire devices
      numberOfDevices = sensors.getDeviceCount();
  
      sprintf(printstring,"sensors.getDeviceCount found %d Devices \n", numberOfDevices);
      logOut(printstring, msgDS18B20Info, msgInfo);

      numberOfDevices = noDS18B20Sensors;   // number of DS18B20 expected; /// temporary
      // Setzen der Genauigkeit
      for(i=0; i<numberOfDevices; i++) {
        if(sensors.getAddress(tempDeviceAddress, i)) {
          sensors.setResolution(tempDeviceAddress, TEMPERATURE_PRECISION);
          Serial.print(F("Sensor "));
          Serial.print(i);
          Serial.print(F(" had a resolution of "));
          Serial.println(sensors.getResolution(tempDeviceAddress), DEC);
        }
      }
      Serial.println("");
      numberOfDevices = sensors.getDeviceCount();   // does not function with OneWire library 2.3.5 (claimed to be ok with 2.3.3)
      sprintf(printstring,"Found %d sensors\n", numberOfDevices);
      logOut(printstring, msgDS18B20Info, msgInfo);
      esp_task_wdt_reset();   // keep watchdog happy

      // code 2: find devices by searching on the onewire bus across all addresses. 
      // workaround, works apparently for ESP32

      sprintf(printstring,"Searching 1-Wire-Devices...\n\r");// "\n\r" is NewLine
      logOut(printstring, msgDS18B20Info, msgInfo);
      
      //critical section. Could help with incorrect sensor detection
      // https://docs.espressif.com/projects/esp-idf/en/latest/esp32/api-guides/freertos-smp.html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
      //portMUX_TYPE myMutex = portMUX_INITIALIZER_UNLOCKED;
      //portENTER_CRITICAL(&myMutex);
      #ifdef isBLYNK
        Blynk.disconnect();
        delay(1500);
      #endif  

      crcCheck = true;  // reset crc Check flag
      for(j=1; j<=20 ; j++)
      {
        noDS18B20Connected = 0;
        oneWire.reset_search(); // reset search of oneWire devices
        delay(100);
        while(sensors.getAddress(addr, noDS18B20Connected)) {  

          sprintf(printstring,"1-Wire-Device %d found with Adress: ", noDS18B20Connected);
          // logOut(printstring, msgDS18B20Info, msgInfo);
          esp_task_wdt_reset();   // keep watchdog happy

          // Fletcher checksum algorithm https://de.wikipedia.org/wiki/Fletcher%E2%80%99s_Checksum 
          checksum[noDS18B20Connected] = 0;
          sum1=0;
          sum2=0;
          for( i = 0; i < 8; i++) {
            DS18B20Address[noDS18B20Connected][i] = addr[i];
            sum1 = (sum1 + addr[i]) % 255;
            sum2 = (sum2 + sum1) % 255;
            //checksum[noDS18B20Connected] += (i+1)*addr[i];
            // Serial.print("0x");
            /*
            if (addr[i] < 16) {
            strcat(printstring,"0");
            }
            sprintf(printstring,"%s%d",printstring, addr[i]);
            if (i < 7) {
              strcat(printstring," ");
            }
            */
          }
          checksum[noDS18B20Connected] = 256 * sum1 + sum2; // checksum is two sub-sums combined
          // strcat(printstring,"\n");
          //logOut(printstring, msgDefaultID, msgInfo);
          if ( OneWire::crc8( addr, 7) != addr[7]) {
            // sprintf(printstring,"CRC is not valid!\n\r");
            // logOut(printstring, msgDS18B20Info, msgWarn);
            crcCheck = false;
            //return;
          }
          noDS18B20Connected ++;    // one more device found
        } // while

        // check if no two addresses are identical
        check = true;
        /*
        for(i = 1; i<noDS18B20Connected; i++){
          if(checksum[i] == checksum[i-1])
            check = false; 
        }
        */
        for(i = 1; i<noDS18B20Connected; i++)
          for(k = 0; k<i; k++)
            if(checksum[i] == checksum[k])
              check = false; 

        if ((noDS18B20Connected >= noDS18B20Sensors) && (check == true)) // exit for loop if expected number of sensors has been found
          break;
        delay(j * 100);
      } // for j
      #ifdef isBLYNK
        Blynk.connect();
        delay(600);
      #endif  
      //portEXIT_CRITICAL(&myMutex); // exit critical section
      noRepeats++;
    }while((check==false || crcCheck==false) && noRepeats < 3); // repeat until the check is true

    sprintf(printstring,"Check: %d \n", check);
    logOut(printstring, msgDS18B20Info, msgInfo);
    sprintf(printstring,"Found 1-Wire-Devices: %d in %d loop runs\n", noDS18B20Connected, j);
    logOut(printstring, msgDS18B20Info, msgInfo);

    for(j=0 ; j< noDS18B20Connected; j++) 
    {
      sprintf(printstring, "Addr [%d] (Checksum: %ld): ", j, checksum[j]);
      for( i = 0; i < 8; i++) {
        // Serial.print(DS18B20Address[noDS18B20Connected][i], HEX);
        // Serial.print(" ");
        itoa(DS18B20Address[j][i], ps, 16);
        strcat(printstring, ps); 
        strcat(printstring," ");
      }
      strcat(printstring,"\n");
      logOut(printstring, msgDS18B20Info, msgInfo);
    }  
    oneWire.reset_search(); // reset search of oneWire devices
    
    return;
  }

  /**************************************************!
  @brief    Complete restart of the DS18B20 measurement function, incl. parallel running meas. function
  @details  Terminates the detached task (Task1) running to do DS10B20 measurements in parallel
            Switches power for the 1Wire bus off for 2 seconds, then on again.
            Then determines the number and addresses of DS18B20 sensors
            And finally restarts the measuring function running in parallel as Task1 (GetOneDS18B20Temperature)
  @param    none
  @return   void
  ***************************************************/
  void restartDS18B20MeasurementFunction()
  {
    noDS18B20Restarts++;
    sprintf(printstring,"XXXX Restarting DS18B20 measuring function XXXX !!! %d \n", noDS18B20Restarts);
    logOut(printstring, msgDS18B20Restart, msgWarn);  
    stopDS18B20MeasureFlag = true;   // use this flag to stop measurements with DS18B20
    esp_task_wdt_reset();   // keep watchdog happy

    vTaskDelete(Task1);              // delete the measurement task

    // switch off Power (via GPIO 32)
    pinMode(POWER_ONEWIRE_BUS, OUTPUT);
    digitalWrite(POWER_ONEWIRE_BUS, LOW);
    vTaskDelay(2000 / portTICK_PERIOD_MS); // delay for 2000 ms
    esp_task_wdt_reset();   // keep watchdog happy

    // switch on Power (via GPIO 32)
    pinMode(POWER_ONEWIRE_BUS, OUTPUT);
    digitalWrite(POWER_ONEWIRE_BUS, HIGH);
    vTaskDelay(300 / portTICK_PERIOD_MS); // delay for 1000 ms
    // Start OneWire for DS18B20
    sensors.begin();
    vTaskDelay(700 / portTICK_PERIOD_MS); // delay for 1000 ms

    adresseAusgeben();       // find addresses of DS18B20 devices
    esp_task_wdt_reset();    // keep watchdog happy

    // Create GetTemperature task for core 0, loop() runs on core 1
    xTaskCreatePinnedToCore(
      GetOneDS18B20Temperature, /* Function to implement the task */
      "Task1", /* Name of the task */
      10000,  /* Stack size in words */
      NULL,  /* Task input parameter */
      0,  /* Priority of the task. higher number is higher priority, https://esp32.com/viewtopic.php?t=10629 */
      &Task1,  /* Task handle. */
      1); /* Core where the task should run */
    stopDS18B20MeasureFlag = false; // reset flag to start measurements
  }

  // manual restart via V60
  #ifdef isBLYNK
    BLYNK_WRITE(V60) 
    {
      int x = param.asInt();
      sprintf(printstring,"Manual restart of DS18B20 initiated %d\n", x);
      logOut(printstring, msgDS18B20Restart, msgWarn);
      if(x==1)  
        manualDS18B20Restart = 1;
      else  
        manualDS18B20Restart = 0;
    }
  #endif // isBLYNK  

#endif  // DS18B20
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
void loop()
{
  #if defined isThingspeak || defined isVirtuino || defined isBME280 || defined isBME680 || defined isOneDS18B20
    mainHandlerTimer.run();   // simple timer for main handler
  #endif
  #if defined isRelay && defined isFan
    fanHandlerTimer.run();    // simple timer for fan handler 
  #endif  
  #if defined isWindowOpenDetector
    windowOpenHandlerTimer.run();    // simple timer for window open handler 
  #endif  
  #ifdef isThingspeak
    thingspeakHandlerTimer.run(); // simple timer for thingspeak data sender handler
  #endif  
  #ifdef isMQTT
    mqttHandlerTimer.run(); // simple timer for MQTT data handler
  #endif  

  // and this is the version for Blynk timer. One for all, but needs Blynk
  MyBlynkTimer.run(); // EXPDis
  #ifdef isBLYNK 
    // EXPDis MyBlynkTimer.run();
  #endif  

  #ifdef isVirtuino 
    virtuinoRun(); // Necessary function to communicate with Virtuino. Client handler
  #endif  
  //*** Blynk communication
  #ifdef isBLYNK
    Blynk.run(); 
  #endif  
 
  // handle OTA over the air Updates 
   #ifdef isOTA
    ArduinoOTA.handle();
  #endif
}

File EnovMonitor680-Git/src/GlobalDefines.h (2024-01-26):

/******************************************************
* Global defines Header file for EnvMonitor680.cpp
*******************************************************/
 
#define PROGNAME  "EnvMonitorBME680"
#ifndef VERSION     // VERSION from platformio.ini
    #define PROGVERSION "V0.124"
#else
    #define PROGVERSION VERSION 
#endif        
#ifndef BUILD_DATE     // Build date from platformio.ini
    #define PROGDATE "2023-09-19"
#else
    #define PROGDATE BUILD_DATE 
#endif   
#define PROGTIME BUILD_TIME

// !!! use only one option that sends or receives data from serial!
#undef isBLYNK         // EXPDis BLYNK Connection enabled. This is the one and only central switch for blynk!
    #undef blynkRestartHouly // if defined, Blynk is restarted on an hourly base, for unsteady connections
    #define blynkRegularCheck // EXPDis if defined, checkBlynk called() regularly by timer to reconnect

    #define blynkLocalIP    192,168,178,64  // IP address for local Blynk server
    #define blynkTerminal   // terminal output to virtual pin V50 

 // defines to determine the correct HW configuration, incl. auth string and calibration values. ONE ONLY!
 // may be automated via env. variables, see https://community.platformio.org/t/using-preprocessor-directives-defined-in-platformio-ini/24169 

 // #define blynkWebHinkelhurz
 // #define blynkBME680Kueche
 // #define blynkKuecheLinks
 // #define blynkEnvLocal2Bad
 // #define blynkInfactoryExternalS  // KombiSensorExt-LCD. LCD in Black Box 
 // #define blynkSenseAirRedBox
 // #define blynkKombinsensor1    // KombiSensorExt-OLED. OLED in Black Box, Arduino, BME280, 2 DS18B20 
 // #define blynkWohnzimmerRechts
 // #define blynkBME680BreadBoard    // BME680 auf Breadboard
 // #define blynkRedBoxYellowButton
 // #define virtuinoTestbed          // testbed for virtuino and MQTT, started 27.10.21
 // #define blynkArbeitszimmerPrintedRed
 // #define blynkWohnziLinksPrintedBlack


// attempt to automate the HW configuration based on Platform IO ENV that is selected
#ifndef BUILD_ENV_NAME
    #error "Add -D BUILD_ENV_NAME=$PIOENV to platformio.ini build_flags"
#else
    #define USB_upload  100
    #define OTA_upload_WohnzimmerRe 101
    #define OTA_upload_EnvLocalSenseAirRedBox 102
    #define OTA_upload_EnvLocal2Bad 103
    #define OTA_upload_Schlafzimmer 104
    #define OTA_upload_KombiSensorExtLCD 105
    #define OTA_upload_KombiSensorExt1 106
    #define OTA_upload_kueche 107
    #define OTA_upload_BME680Breadboard 108
    #define OTA_upload_RedBoxYellowBtn 109
    #define OTA_upload_ArbeitszimmerPrintedRed 110
    #define OTA_upload_WohnziLinksPrintedBlack 111
#endif

#if BUILD_ENV_NAME==USB_upload  // needs to be manually selected in case of USB Upload ENV
 // #define blynkWebHinkelhurz
  #define blynkBME680Kueche
 // #define blynkKuecheLinks
 // #define blynkEnvLocal2Bad
 // #define blynkInfactoryExternalS  // KombiSensorExt-LCD. LCD in Black Box 
 // #define blynkSenseAirRedBox
 // #define blynkKombinsensor1       // KombiSensorExt-OLED. OLED in Black Box, Arduino, BME280, 2 DS18B20 
 // #define blynkWohnzimmerRechts
 // #define blynkBME680BreadBoard    // BME680 auf Breadboard
 // #define blynkRedBoxYellowButton
 // #define blynkArbeitszimmerPrintedRed    // new sensor 07.02.23 in red printed housing
 // #define blynkWohnziLinksPrintedBlack //new sensor 10.02.23 in red printed housing
 // #define virtuinoTestbed          // testbed for virtuino and MQTT, started 27.10.21
#elif BUILD_ENV_NAME==OTA_upload_WohnzimmerRe
    #define blynkWohnzimmerRechts
#elif BUILD_ENV_NAME==OTA_upload_EnvLocalSenseAirRedBox
    #define blynkSenseAirRedBox
#elif BUILD_ENV_NAME==OTA_upload_EnvLocal2Bad
    #define blynkEnvLocal2Bad
#elif BUILD_ENV_NAME==OTA_upload_KuecheLinks
    #define blynkKuecheLinks
#elif BUILD_ENV_NAME==OTA_upload_KombiSensorExtLCD
    #define blynkInfactoryExternalS
#elif BUILD_ENV_NAME==OTA_upload_KombiSensorExt1
    #define blynkKombinsensor1
#elif BUILD_ENV_NAME==OTA_upload_kueche
    #define blynkBME680Kueche    
#elif BUILD_ENV_NAME==OTA_upload_BME680Breadboard
    #define blynkBME680BreadBoard
#elif BUILD_ENV_NAME==OTA_upload_RedBoxYellowBtn
    #define blynkRedBoxYellowButton    
#elif BUILD_ENV_NAME==OTA_upload_ArbeitszimmerPrintedRed
    #define blynkArbeitszimmerPrintedRed  
#elif BUILD_ENV_NAME==OTA_upload_WohnziLinksPrintedBlack
    #define blynkWohnziLinksPrintedBlack 
#else
    #error "BUILD_ENV_NAME NOT RECOGNIZED"
#endif
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

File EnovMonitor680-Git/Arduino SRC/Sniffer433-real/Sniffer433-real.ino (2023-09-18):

//********************************************************************************************
// Convert 433MHz RF signal created by Temp/Hydro 433 MHz Sensor Infactory NC5849 
// and send them to serial output, for use by other devices (e.g. ESP32
// Written by Markus Preidel 
// Based on work by Ray Wang (Rayshobby LLC)
// http://rayshobby.net/?p=8998
// https://rayshobby.net/reverse-engineer-wireless-temperature-humidity-rain-sensors-part-1/ 
//********************************************************************************************
// 16.08.22: did not work at high temperatures. changes:
// doubled tolerances (particularly for 8000 ms Sync Impulses - tend to get to 8400
// Added upper tolerance of 20000 to get rid of long signals (translated to -1 = 65535)
// Still, signals appear to be pretty bad.
// 15.10.22: correct check for availabilty of serial port. if(mySerial) instead of if(mySerial.available), which is for read only
// 12.09.23: still problems with high temperatures. TOL3 changed from 2*250 to 4*250. Compile on old PC with Arduino IDE
//********************************************************************************************
#include <SoftwareSerial.h>
#define sendSERIAL        // send data via serial
#undef receiveSERIAL      // not used, for future enhancement
#undef sendSERIALERRORS  // only if this is set errors are sent via serial to ESP32

// ring buffer size has to be large enough to fit
// data between two successive sync signals
#define RING_BUFFER_SIZE  256
#define HI_FILTER 20000 // all larger are ignored
#define LO_FILTER 200 // all smaller are ignored
int bitsReceived = 0;

//                          __                 __                  
// NC-3982 Sync:  |________| |________________| |________________|    data bits follow
// time in ms          4   ,5       8,03      .5     8.03 
//                    _
//  data bits: "1":  | |______|
//  time in ms       .6  4.0
//                    _
//  data bits: "0":  | |___| 
//  time in ms       .6  2.0

#define PROGNAME  "Sniffer433_real.cpp"
#define PROGDATE  "2022-09-12"
#define PROGVERSION "V0.13"

#undef outputDATA
#undef  outputSERIALDEBUG

#define NO_SYNC_PULSES 6   // the sync sequence is 4 levels long, plus 1 bit (2 level after the signal = 6)
#define NO_SIGNAL_PULSES 82 // signal is 41 bit long  

#define SYNC_LENGTHI 540
#define SYNC_LENGTH 4000

#define SYNC_HIGH  540
#define SYNC_LOW   8000
#define BIT1_HIGH  540
#define BIT1_LOW   4050
#define BIT0_HIGH  540
#define BIT0_LOW   2050

#define TOL1  2*80  // tolerance values
#define TOL2 2*150   
#define TOL3 4*250 

#define DATAPIN  3  // D3 is interrupt 1
#define TRIGGERPIN 12 // to trigger scope

volatile unsigned int timings[RING_BUFFER_SIZE];
volatile unsigned int syncIndex1 = 0;  // index of the first sync signal
volatile unsigned int syncIndex2 = 0;  // index of the second sync signal
volatile unsigned int changeCount = 0;
volatile unsigned int syncCount = 0;
volatile bool received = false;

unsigned char resultbuffer[10]; // byte buffer for payload

// Variables for automatic adaptation of pulse lengths
unsigned int Bit1_High_Lengths = BIT1_HIGH;
unsigned int Bit1_Low_Lengths = BIT1_LOW;
unsigned int Bit0_High_Lengths = BIT0_HIGH;
unsigned int Bit0_Low_Lengths = BIT0_LOW;

// Variables for pulse statistics

unsigned long lastOutput=0;
unsigned int messagesReceived=0, messagesDropped=0;
unsigned int count1=0,  sum1HI=0,  sum1LO=0, max1HI=0,  min1HI=1000000,  max1LO=0, min1LO=1000000;
unsigned int count0=0,  sum0HI=0,  sum0LO=0, max0HI=0,  min0HI=1000000,  max0LO=0, min0LO=1000000;
unsigned int counts2=0, sums2HI=0, sums2LO=0,maxs2HI=0, mins2HI=1000000, maxs2LO=0, mins2LO=1000000;
unsigned int counts1=0, sums1HI=0, sums1LO=0,maxs1HI=0, mins1HI=1000000, maxs1LO=0, mins1LO=1000000;
unsigned int countsy=0, sumsyHI=0, sumsyLO=0,maxsyHI=0, minsyHI=1000000, maxsyLO=0, minsyLO=1000000;

// other global ariables
char printstring[100];

// macros to set and to get bits in a bitfield
// http://www.mathcs.emory.edu/~cheung/Courses/255/Syllabus/1-C-intro/bit-array.html
#define SetBit(A,k)     ( A[(k/8)] |= (1 << (k%8)) )   
#define ClearBit(A,k)   ( A[(k/8)] &= ~(1 << (k%8)) )    
#define TestBit(A,k)    ( A[(k/8)] & (1 << (k%8)) )     

//--- print a byte as bits
void  print_bits(unsigned char octet)
{
    int z = 128, oct = octet;

    while (z > 0)
    {
        if (oct & z)
            Serial.print("1");
        else
            Serial.print("0");
        z >>= 1;
    }
}

// reverse bit order in byte
uint8_t reverse8(uint8_t x)
{
    x = (x & 0xF0) >> 4 | (x & 0x0F) << 4;
    x = (x & 0xCC) >> 2 | (x & 0x33) << 2;
    x = (x & 0xAA) >> 1 | (x & 0x55) << 1;
    return x;
}

bool isSync3489(unsigned int idx) {
  // check if we've received a short high followed by a long low
  volatile unsigned long t0, tm1, tm2, tm3; 
  volatile unsigned int i;
  i=idx+RING_BUFFER_SIZE;
  t0 = timings[(idx+RING_BUFFER_SIZE) % RING_BUFFER_SIZE];
  tm1 = timings[(idx+RING_BUFFER_SIZE-1) % RING_BUFFER_SIZE];
  tm2 = timings[(idx+RING_BUFFER_SIZE-2) % RING_BUFFER_SIZE];
  tm3 = timings[(idx+RING_BUFFER_SIZE-3) % RING_BUFFER_SIZE];   
  if(tm3<(SYNC_HIGH-TOL1) || tm3>(SYNC_HIGH+TOL1) ||
     tm2<(SYNC_LOW-TOL3)  || tm2>(SYNC_LOW+TOL3) ||
     tm1<(SYNC_HIGH-TOL1) || tm1>(SYNC_HIGH+TOL1) ||
     // +++test     t0<(SYNC_LOW-TOL3)  || t0>(SYNC_LOW+TOL3)) 
     t0<(SYNC_LOW-TOL3)) 
  {
    return false;
  }
  digitalWrite(TRIGGERPIN, HIGH); // make sync signal for scope
  return true;
}
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

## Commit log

2021-05-09 Initial commit of Pictures and Kicad files
    [EnvMonitor-B_Cu.gbr, EnvMonitor-B_Mask.gbr, EnvMonitor-B_Paste.gbr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]
2021-05-09 Added Arduino HW and SW
    [Arduino433Receiver.kicad_pcb, Arduino433Receiver.sch]
2021-05-10 Readme.md updated: Blynk virtual pin list added
2021-05-12 loop to main_handler, display and main_handler via timers
2021-05-13 Improved OLED&LCD switching. Improved timer handling
2021-05-16 Display off via timer implemented
2021-05-16 displays switched off via timer improved
2021-05-18 DS18B20->Blynk: compare with wrong (cal) value, corrected
    [EnvMonitorBME680.cpp, GlobalDefines.h]
2021-05-24 LED Heartbeat added on PIN 14 (HEARTBEATPIN)
2021-05-26 -DBOARD_HAS_PSRAM -mfix-esp32-psram-cache-issue
2021-06-04 V0.53 BME680 restart attemts, if error -2
    [EnvMonitorBME680.cpp, EnvMonitorBME680.h, GlobalDefines.h]
2021-06-18 V0.54 Extended Blynk startup if server connect fails
    [EnvMonitorBME680.cpp, GlobalDefines.h]
2021-06-24 resetBME680 triggered by bme680Status as well
    [EnvMonitorBME680.cpp, EnvMonitorBME680.h, GlobalDefines.h]
2021-08-08 resetBME680 now by toggling power via relay2
    [EnvMonitorBME680.cpp, GlobalDefines.h]
2021-08-10 Counter for PowerToggles BME680 added
2021-08-13 Imroved output for BME680 power toggles
2021-10-01 Improved Handling of NTP server connections, in case of failure (here due to PI-Hole having to be restarted)
    [EnvMonitorBME680.cpp]
2021-11-11 BME680 handling: recovery from error-2 at startup
    [EnvMonitorBME680.cpp, EnvMonitorBME680.h, GlobalDefines.h]
2021-11-11 Blynk%Thingspeak parallel (string too long-solved)
    [EnvMonitorBME680.cpp, GlobalDefines.h]
2021-11-23 Thingspeak added for Infactor 433 MHz sensors via serial
2021-11-24 BME280 to GeneralTestbed, improved Thingspeak timers
2021-11-30 Corrected logics in Thingspeak send for DS18B20
    [EnvMonitorBME680.cpp, GlobalDefines.h]
2021-12-01 Minor error corrections. HTTP timeout set for Thingspeak
    [EnvMonitorBME680.cpp, GlobalDefines.h]
2021-12-14 Improvements Window Open Beeper, silence Button
2021-12-15 Impr.Window Open Beeper Handling & BeepStop button
2022-01-15 Corrected use of DS18B20 for GeneralTestbed to 1
    [EnvMonitorBME680.h, GlobalDefines.h]
2022-02-13 Upd ESP32 Platform to 3.5.0. Libs via lib_depths
2022-03-10 Activate pressure correction BME280&BME680
    [EnvMonitorBME680.cpp, EnvMonitorBME680.h, GlobalDefines.h]
2022-03-13 Correct ntp wrong summer time with time zone string
    [EnvMonitorBME680.cpp]
2022-04-18 Attempt receive data from front infactory sensor
2022-08-24 Improved Glitch recognition Infactory T&H (3656f)
    [EnvMonitorBME680.cpp, GlobalDefines.h]
2022-08-24 Sniffer433 improved: doubled tolerances (particularly for 8000 ms Sync Impulses - tend to get to 8400 Added upper tolerance of 20000 to get rid of long signals (translated to -1 = 65535)
    [Sniffer433-real.ino]
2022-10-14 Thingspeak for LCD device
2022-11-10 Try to prevent zeroes for thingspeak p, t, h
    [EnvMonitorBME680.cpp]
2023-10-23 LCD dimming made optional, new libs, new framework
2023-10-23 LCD dimming made optional, new libraries, new framework
2023-11-04 V0.128 - MQTT corrections (unique clientID)
    [EnvMonitorBME680.cpp, EnvMonitorBME680.h, GlobalDefines.h]
